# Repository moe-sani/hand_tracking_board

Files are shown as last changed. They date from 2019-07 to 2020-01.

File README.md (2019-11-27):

# hand_tracking_board

    branch name: red_55
    hardware version: RT Exo Data v1.0
    Processor: Arduino M0 Pro (Native USB)

* author: Mohammad Fattahi Sani
* Email: fattahi.m91@gmail.com

----------

 This package contains the following branches: 
 * red_55 : this is the branch for teleoperating the davinci and 3 finger tools. this is for small boards
 * master: this branch was used to collect data in surgical tests using 11 sensors and old board with multiplexr
 * red_80 :  small board configured to work with BNO080 sensors (not finalized yet)
 * DEV_BNO080 :  the vidor4000 board configured to work with BNO080 sensors (not finalized yet)

----------

This version is customized for reading 7 BNO55 sensors. The software only reads I2C zero wich is connected to the connectors on the bottom left of the board ( when holding it with usb on the right side)

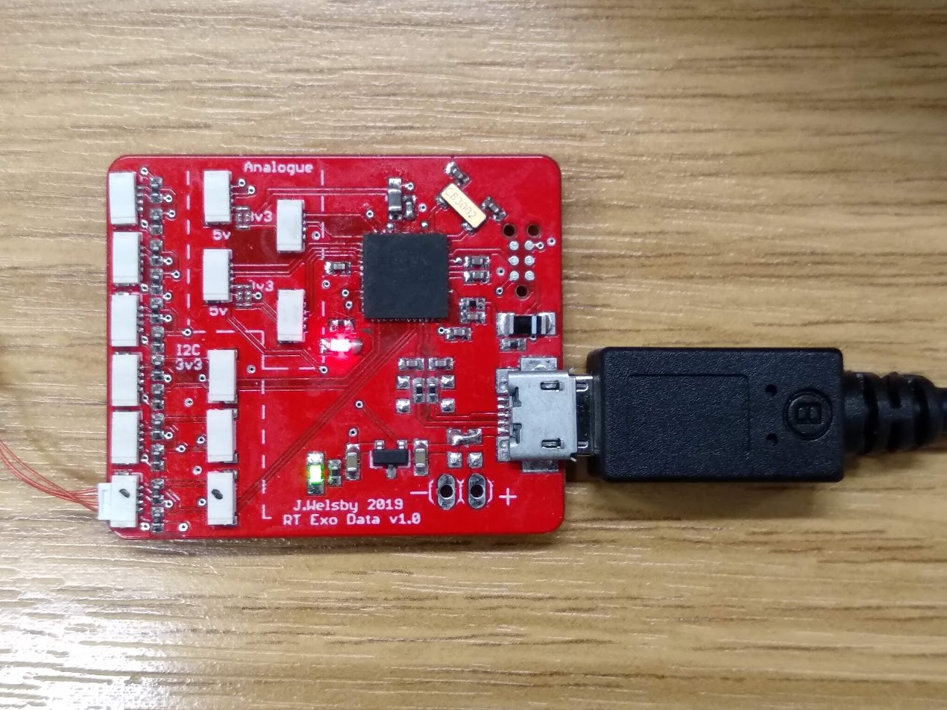
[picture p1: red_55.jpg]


## Sensors:

the sensors must have I2C address translator chip on them. The address on the chip can be selected using the provided resistor values.

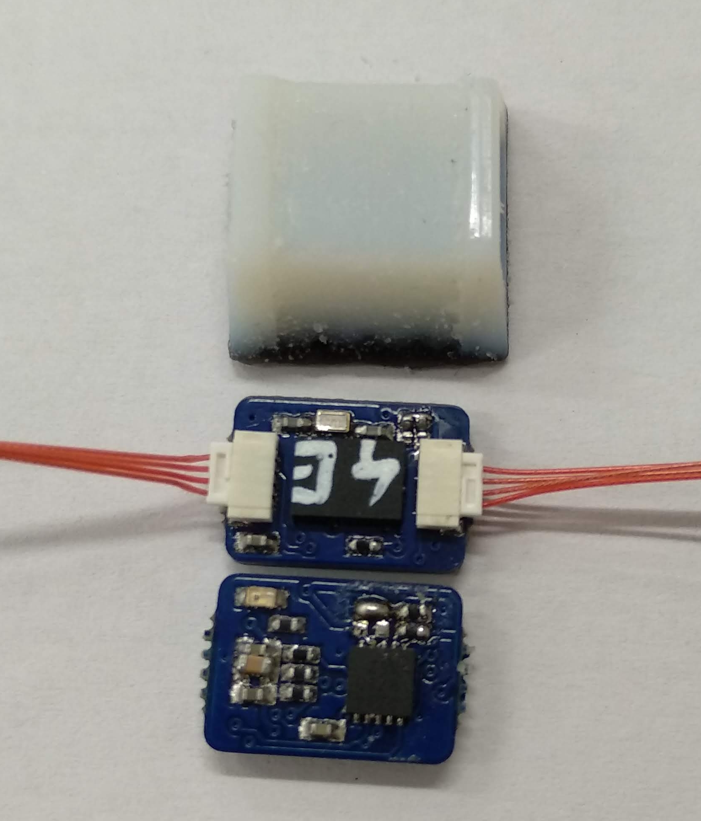
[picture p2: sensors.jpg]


The specific address for each sensor board then should be provided to the software at initializing step of the software. Following is showing how you can set diffrent sensor addresses to the board:

    imu_sensor imu_sensor0=imu_sensor(0,0,0x48);
    imu_sensor imu_sensor1=imu_sensor(1,0,0x28);
    imu_sensor imu_sensor2=imu_sensor(2,0,0x47);
    imu_sensor imu_sensor3=imu_sensor(3,0,0x27);
    imu_sensor imu_sensor4=imu_sensor(4,0,0x2C);
    imu_sensor imu_sensor5=imu_sensor(5,0,0x21);
    imu_sensor imu_sensor6=imu_sensor(6,0,0x68);

This means that for example sensor0 has the address of 0x48. So that specific sensor has be located on the hand on the location defined for sensor0.
## How To Program:

1. you must have arduino program installed on your computer.
2. you must have Arduino M0 Pro (Native USB) driver installed as follows:
    
    navigate to Tools> Boards > Board Manager> install:Arduino SAMD Boards (32-bits ARM Cortex-M0+) by arduino.

3. select the following board: Arduino M0 Pro (Native USB) 

### Required libraries in Arduino:
Please install the following libraries from Arduino Library manager:

    Adafruit BNO055 (version 1.1.8)
    Adafruit Unified Sensor (version 1.0.3)

after you followed the steps, you can simply connect the usb to the board, select the correct usb in the arduino and upload the program.

in the command window, you will first see the initialization steps, for a few seconds, and then the sensor information will be streaming.

here is the sample of data you will see repeatedly:

    > {"S0":[0,0,0,10000], "S1":[3377,-247,-9177,-2073], "S2":[0,0,0,10000], "S3":[0,0,0,10000] }
    > { "C0":[3,3,3,3], "C1":[3,3,3,1], "C2":[3,3,3,3], "C3":[3,3,3,3]} 

the first line is actuall sensory information and the second line is the calibration values (0~3) . 

in this example, it can be noticed that only S1/C1 is connected to the board and the other values are not valid.

    ("S0":[0,0,0,10000]) means that the sensor is not connected).

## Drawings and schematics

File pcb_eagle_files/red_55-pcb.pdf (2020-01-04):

## SAMD21G18A_QFN 100nF ¹⁰⁰nF MH²⁰²⁹⁻³⁰⁰Y

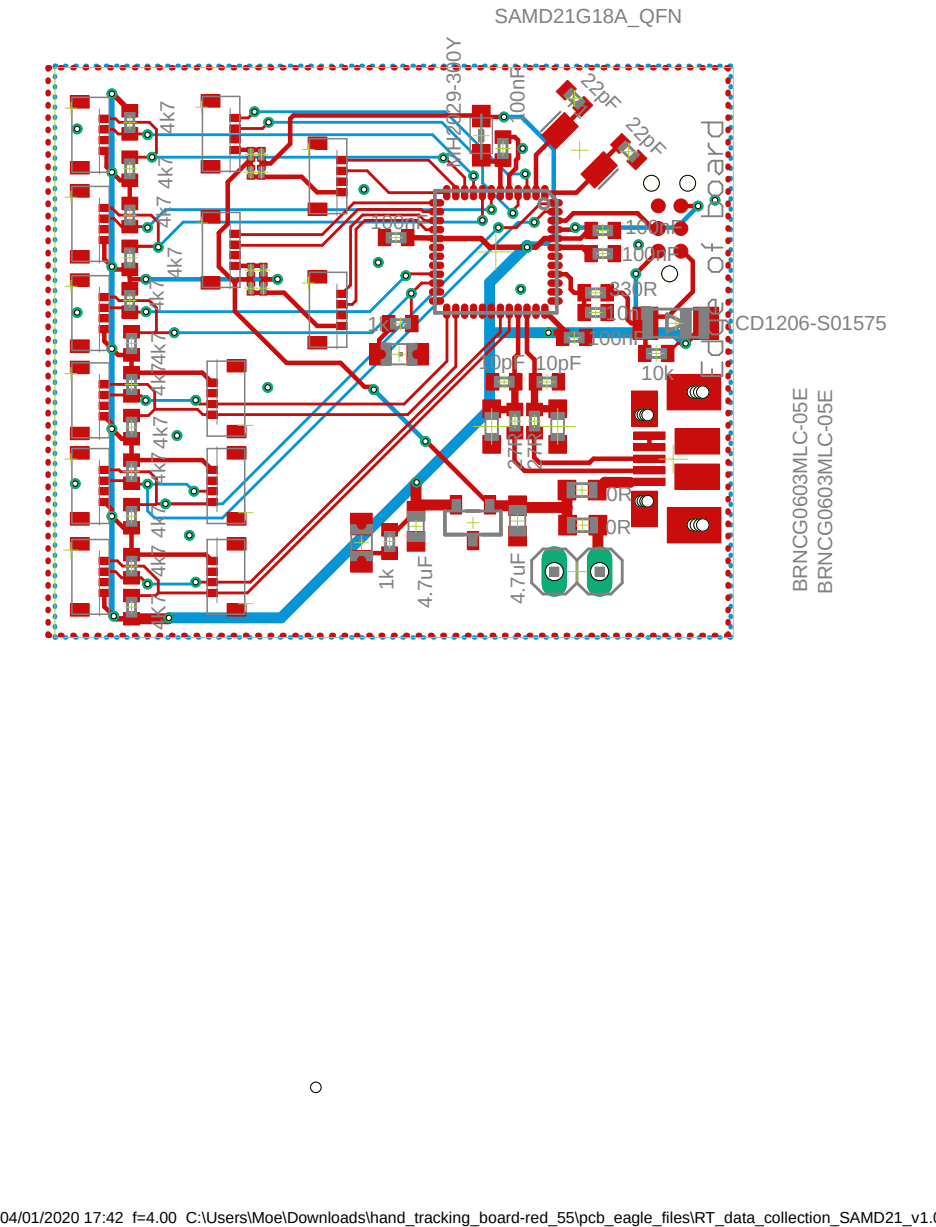
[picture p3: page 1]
BRNCG⁰⁶⁰³MLC⁻⁰⁵E BRNCG⁰⁶⁰³MLC⁻⁰⁵E

04/01/2020 17:42 f=4.00 C:\Users\Moe\Downloads\hand_tracking_board-red_55\pcb_eagle_files\RT_data_collection_SAMD21_v1.0_auto.brd

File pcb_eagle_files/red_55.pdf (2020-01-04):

04/01/2020 17:40 f=0.75 C:\Users\Moe\Downloads\hand_tracking_board-red_55\pcb_eagle_files\RT_data_collection_SAMD21_v1.0_auto.sch (Sheet: 1/3) VDD

# GND +3V³

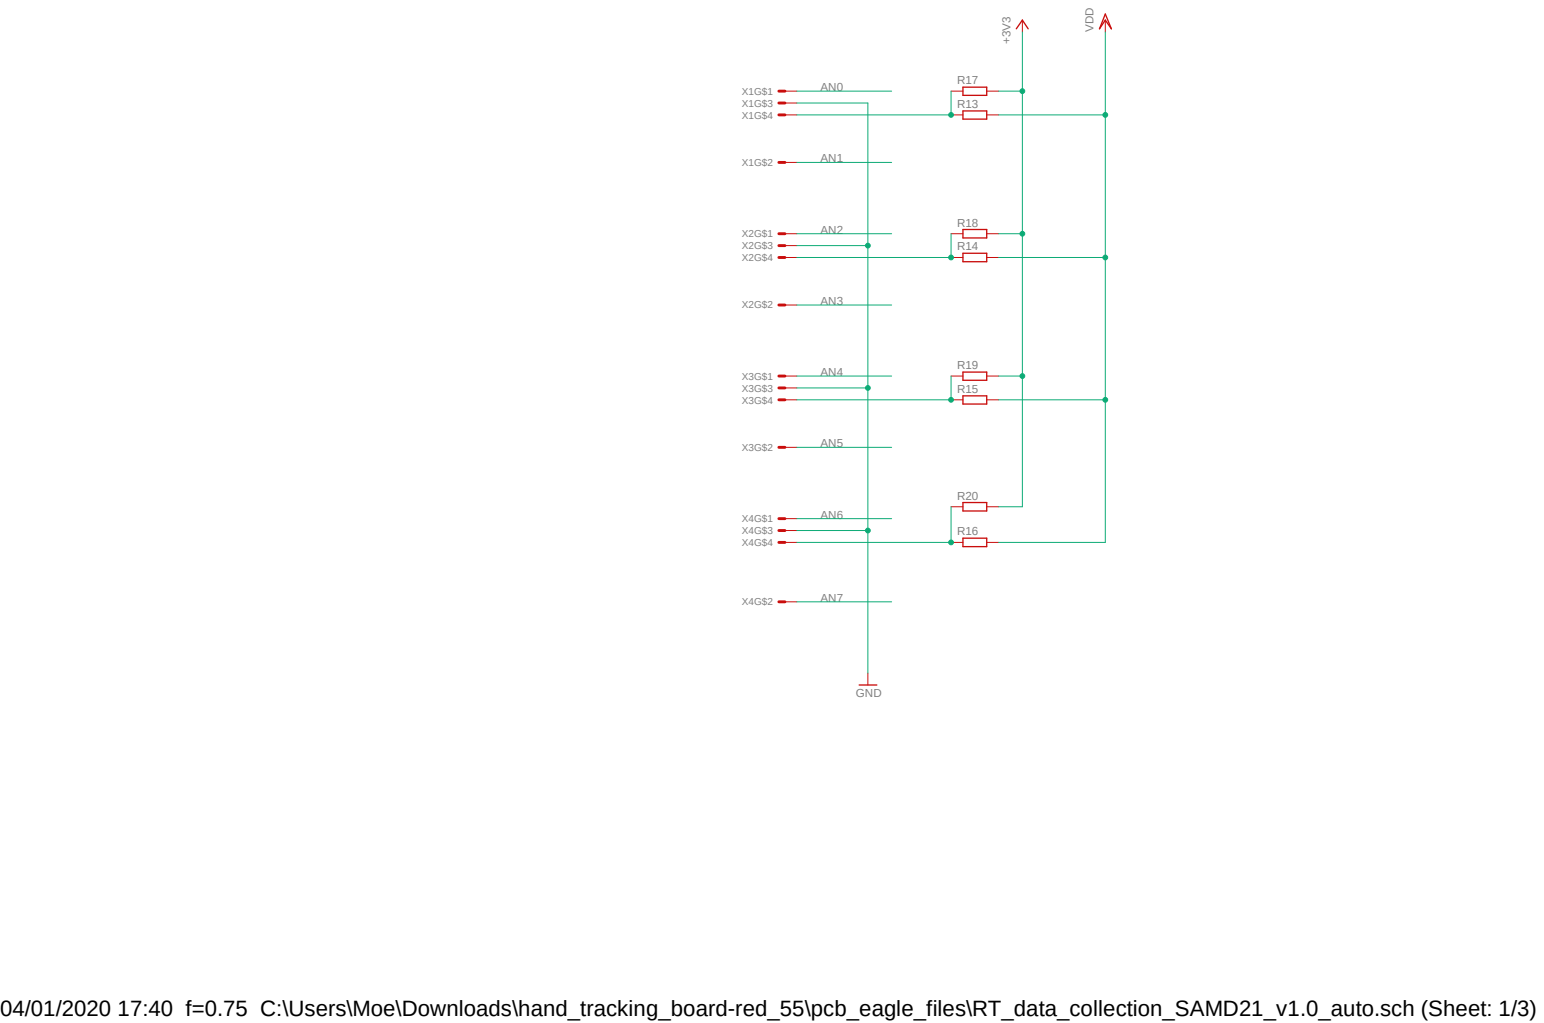
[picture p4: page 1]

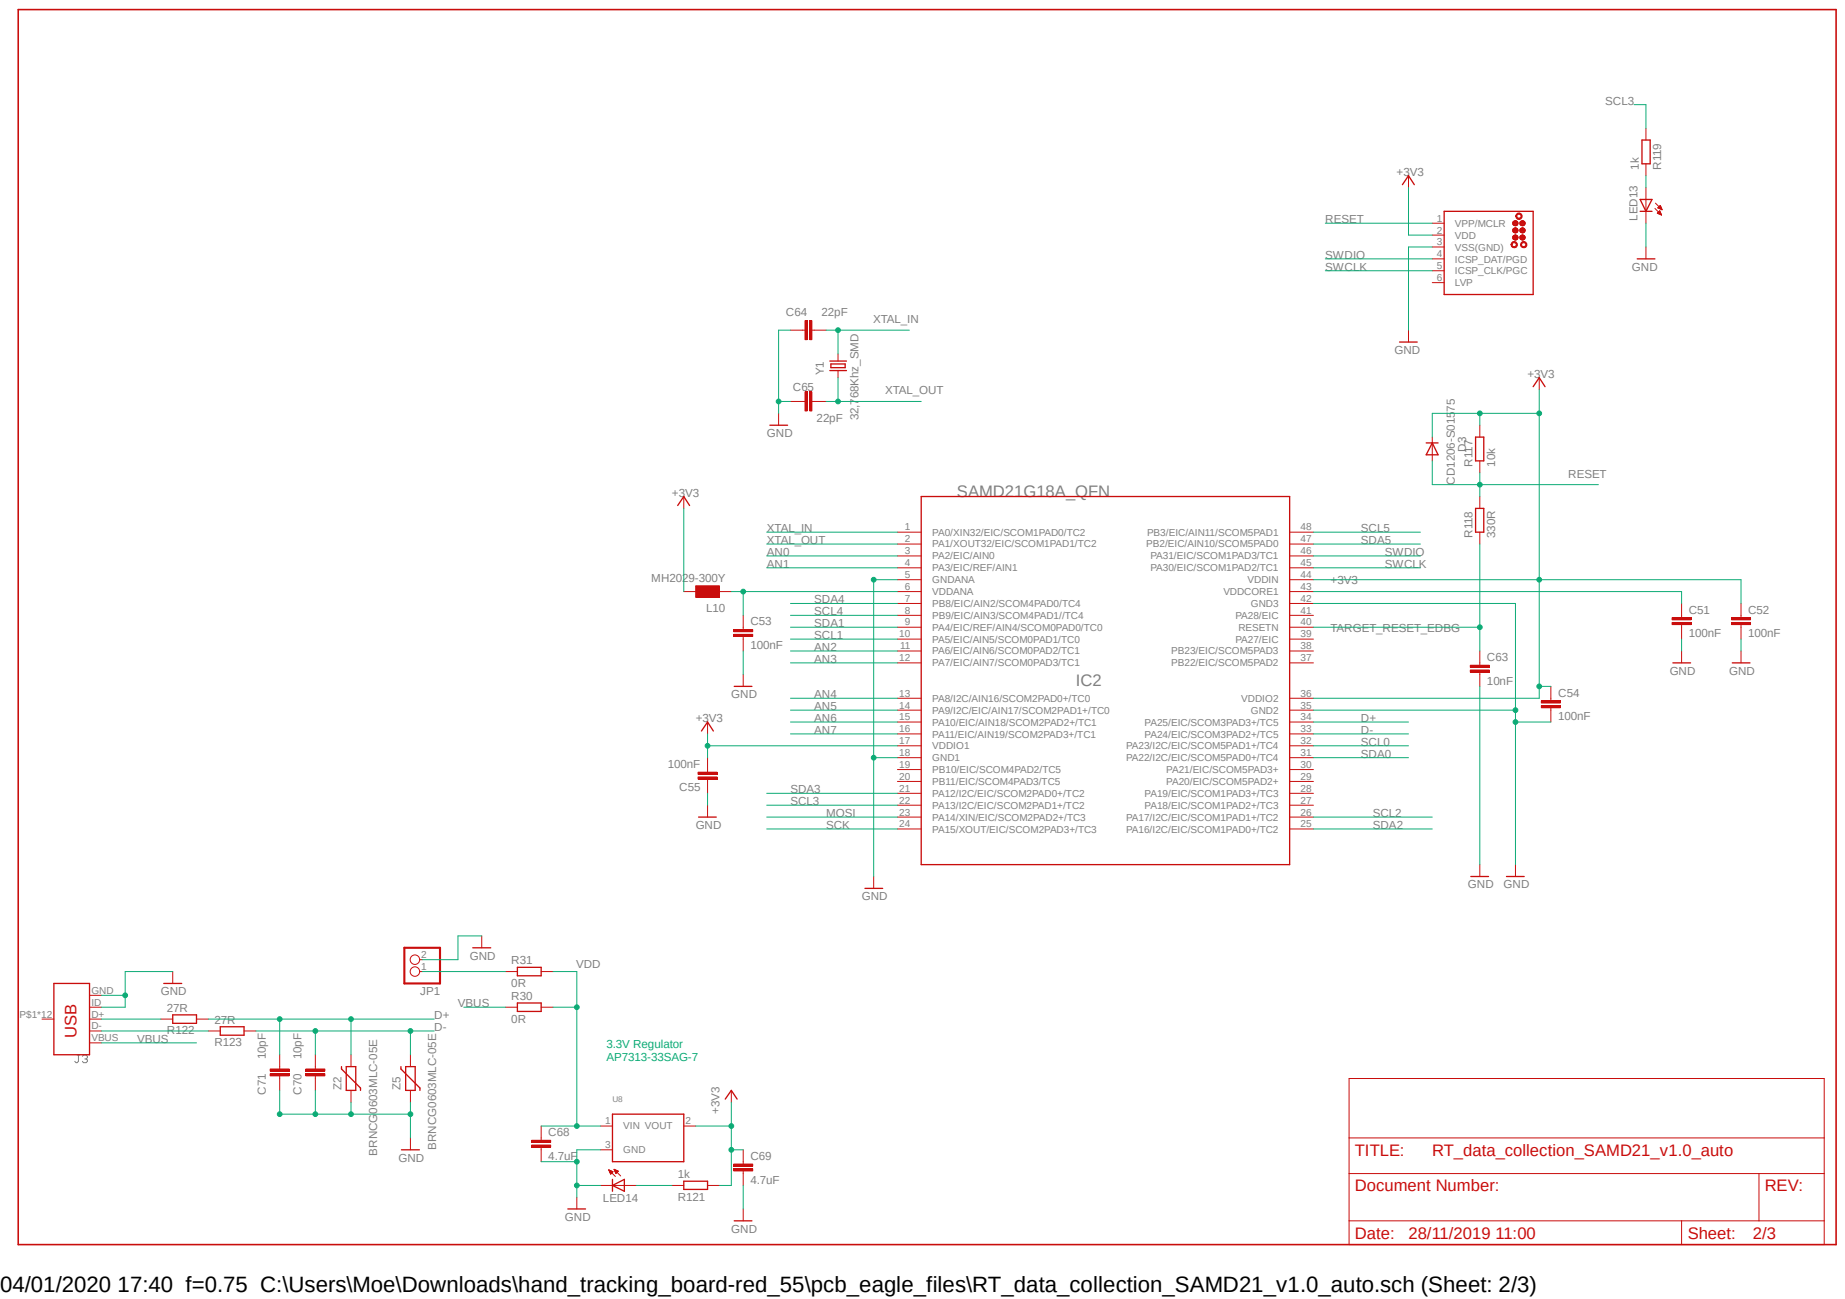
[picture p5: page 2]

GND¹⁰k 330R CD¹²⁰⁶⁻S⁰¹⁵⁷⁵ ³²,768Khz_SMD

C63 R¹¹⁷ R¹¹⁸ D³ Y¹

Document Number: | REV:

Date: 28/11/2019 11:00 | Sheet: 2/3

04/01/2020 17:40 f=0.75 C:\Users\Moe\Downloads\hand_tracking_board-red_55\pcb_eagle_files\RT_data_collection_SAMD21_v1.0_auto.sch (Sheet: 2/3)

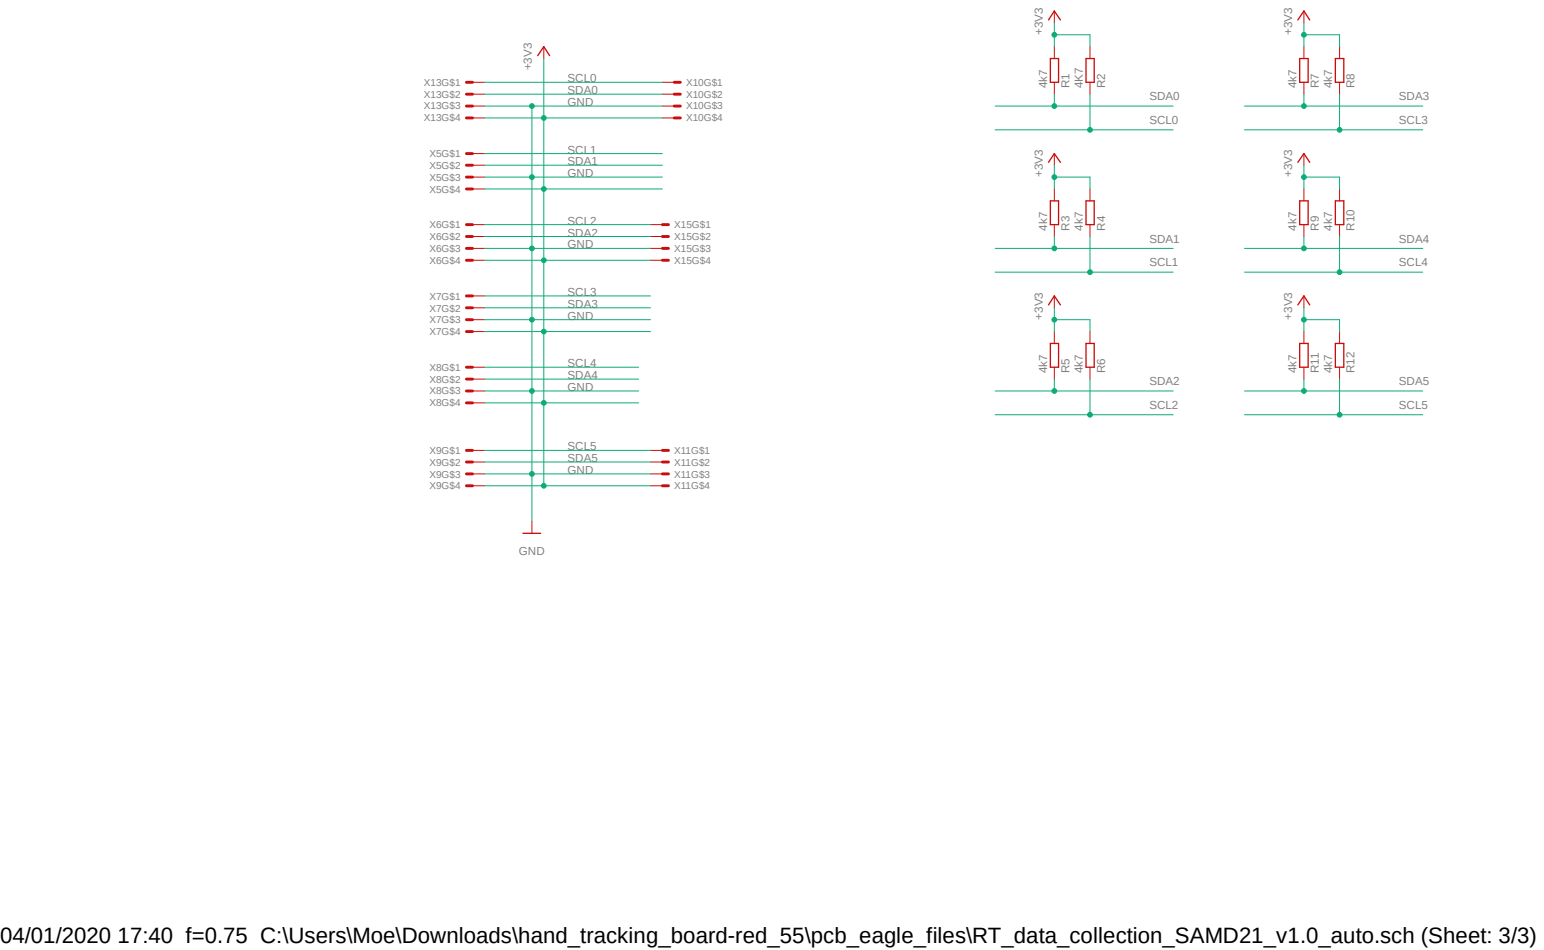
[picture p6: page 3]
GND; R¹⁰ R¹¹; R¹²; SDA0; SCL0; SDA1; SCL1; SDA2; SCL2; SDA4; SCL4; SDA5; SCL5; SDA3; SCL3

04/01/2020 17:40 f=0.75 C:\Users\Moe\Downloads\hand_tracking_board-red_55\pcb_eagle_files\RT_data_collection_SAMD21_v1.0_auto.sch (Sheet: 3/3) ⁺³V³

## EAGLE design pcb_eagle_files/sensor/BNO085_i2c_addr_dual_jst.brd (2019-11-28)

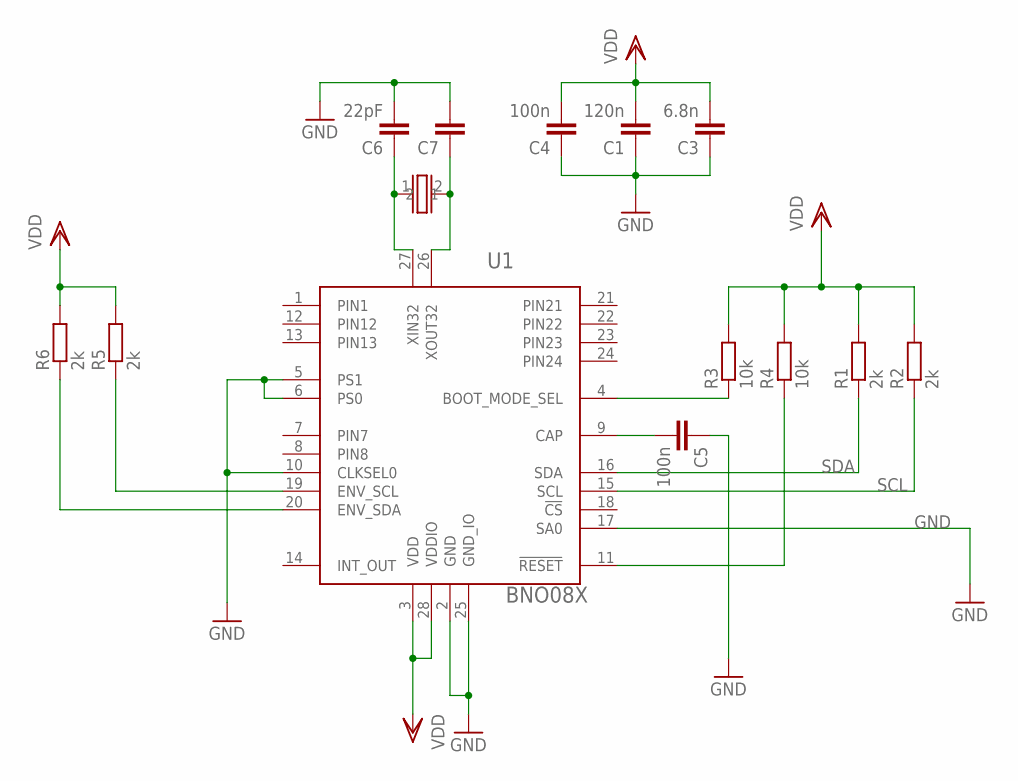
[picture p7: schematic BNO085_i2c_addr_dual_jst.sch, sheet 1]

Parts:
C1: 120n; C0402
C3: 6.8n; C0402
C4, C5: 100n; C0402
C6: 22pF; C0402
C7: C-EUC0402; C0402
R1, R2, R5, R6: 2k; R0402
R3, R4: 10k; R0402
U1: BNO08X; LGA-28_3.80X5.20/0.5
U$1: ABS05

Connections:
GND: C1.1, C3.1, C4.1, C5.1, C6.2, C7.2, U1.2 (GND), U1.5 (PS1), U1.6 (PS0), U1.10 (CLKSEL0), U1.17 (SA0), U1.25 (GND_IO); also elsewhere on the board
unnamed: C6.1, U1.27 (XIN32), U$1.1
unnamed: C7.1, U1.26 (XOUT32), U$1.2
unnamed: C5.2, U1.9 (CAP)
unnamed: R3.1, U1.4 (BOOT_MODE_SEL)
unnamed: R5.1, U1.19 (ENV_SCL)
unnamed: R4.1, U1.11 (!RESET)
unnamed: R6.1, U1.20 (ENV_SDA)
SCL: R2.1, U1.15 (SCL); also elsewhere on the board
SDA: R1.1, U1.16 (SDA); also elsewhere on the board
VDD: C1.2, C3.2, C4.2, R1.2, R2.2, R3.2, R4.2, R5.2, R6.2, U1.3 (VDD), U1.28 (VDDIO); also elsewhere on the board

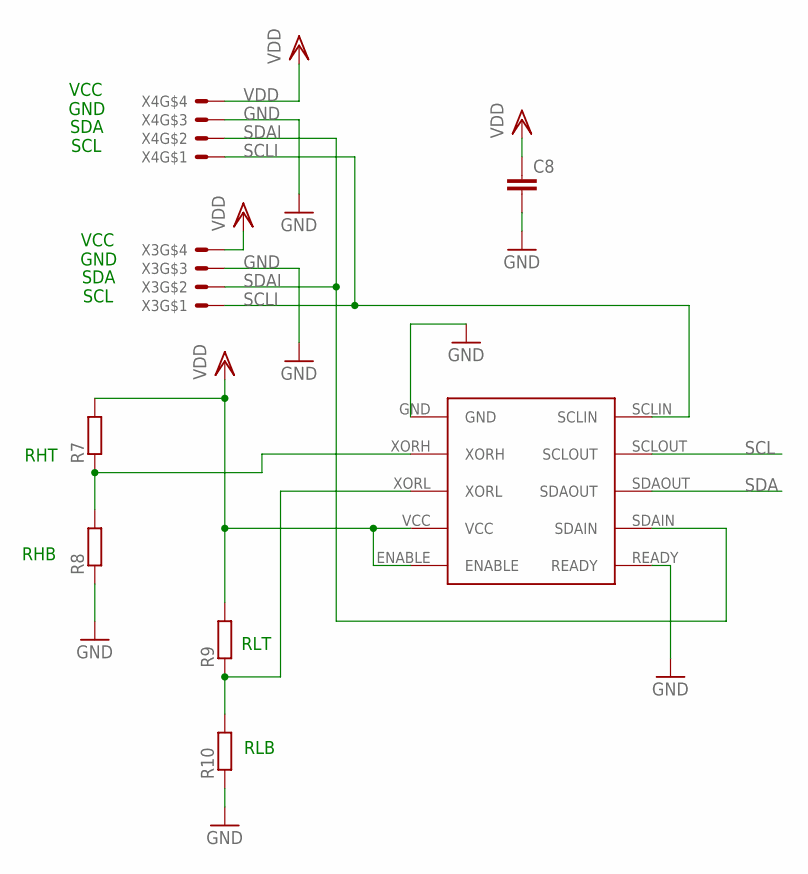
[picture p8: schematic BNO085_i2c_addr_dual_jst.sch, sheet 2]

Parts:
C8: C-EUC0402; C0402
R7, R8, R9, R10: R-EU_R0402; R0402
U$3: LIC4316; DD-DFN-10
X3, X4: SM04B-XSRS; SM04B-XSRS-ETB

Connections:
GND: C8.2, R8.1, R10.1, U$3.GND, U$3.READY, X3.3, X4.3; also elsewhere on the board
unnamed: R7.1, R8.2, U$3.XORH
unnamed: R9.1, R10.2, U$3.XORL
SCL: U$3.SCLOUT; also elsewhere on the board
SCLI: U$3.SCLIN, X3.1, X4.1
SDA: U$3.SDAOUT; also elsewhere on the board
SDAI: U$3.SDAIN, X3.2, X4.2
VDD: C8.1, R7.2, R9.2, U$3.ENABLE, U$3.VCC, X3.4, X4.4; also elsewhere on the board

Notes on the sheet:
SCL
SDA
VCC
GND
RHT
RHB
RLT
RLB

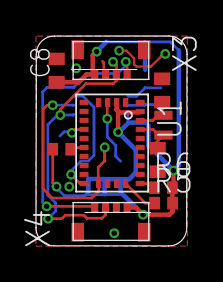
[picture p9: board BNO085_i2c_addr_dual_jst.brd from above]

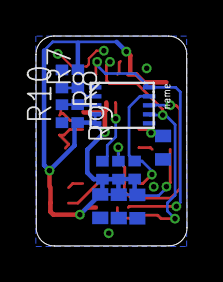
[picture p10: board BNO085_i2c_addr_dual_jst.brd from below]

Board: 2 copper layers, 8.4 x 11.7 mm, 24 parts (12 on the bottom side), 15 nets.

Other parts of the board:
LOGO3: OSHW-LOGOS; OSHW-LOGO-S
U$2: BQ_LOGO_MEDIUM

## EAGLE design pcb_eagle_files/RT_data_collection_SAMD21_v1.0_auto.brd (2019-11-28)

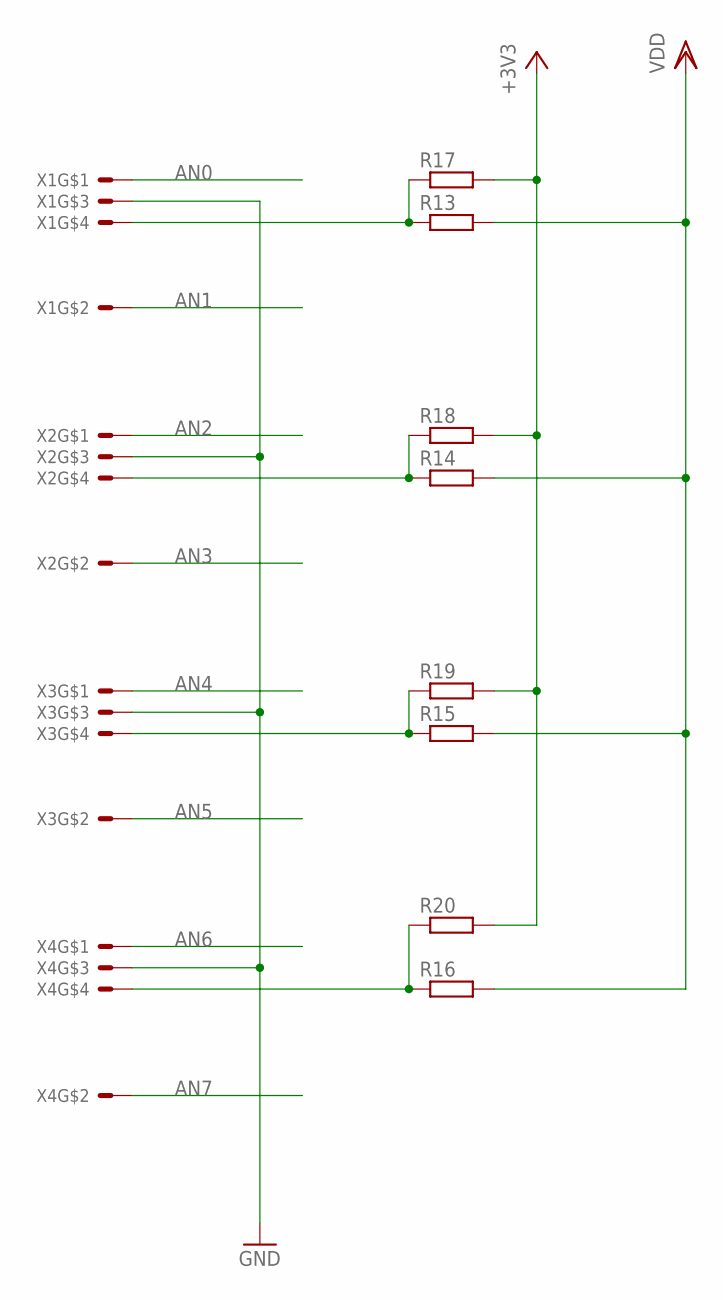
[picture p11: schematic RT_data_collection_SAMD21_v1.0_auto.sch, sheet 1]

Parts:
R13, R14, R15, R16, R17, R18, R19, R20: R-EU_R0201; R0201
X1, X3: CON-JST2_SM04B-XSRS; CON-JST2_SM04B-XSRS-ETB
X2, X4: SM04B-XSRS; SM04B-XSRS-ETB

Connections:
+3V3: R17.2, R18.2, R19.2, R20.2; also elsewhere on the board
AN0: X1.1; also elsewhere on the board
AN1: X1.2; also elsewhere on the board
AN2: X2.1; also elsewhere on the board
AN3: X2.2; also elsewhere on the board
AN4: X3.1; also elsewhere on the board
AN5: X3.2; also elsewhere on the board
AN6: X4.1; also elsewhere on the board
AN7: X4.2; also elsewhere on the board
GND: X1.3, X2.3, X3.3, X4.3; also elsewhere on the board
unnamed: R16.1, R20.1, X4.4
unnamed: R14.1, R18.1, X2.4
unnamed: R15.1, R19.1, X3.4
unnamed: R13.1, R17.1, X1.4
VDD: R13.2, R14.2, R15.2, R16.2; also elsewhere on the board

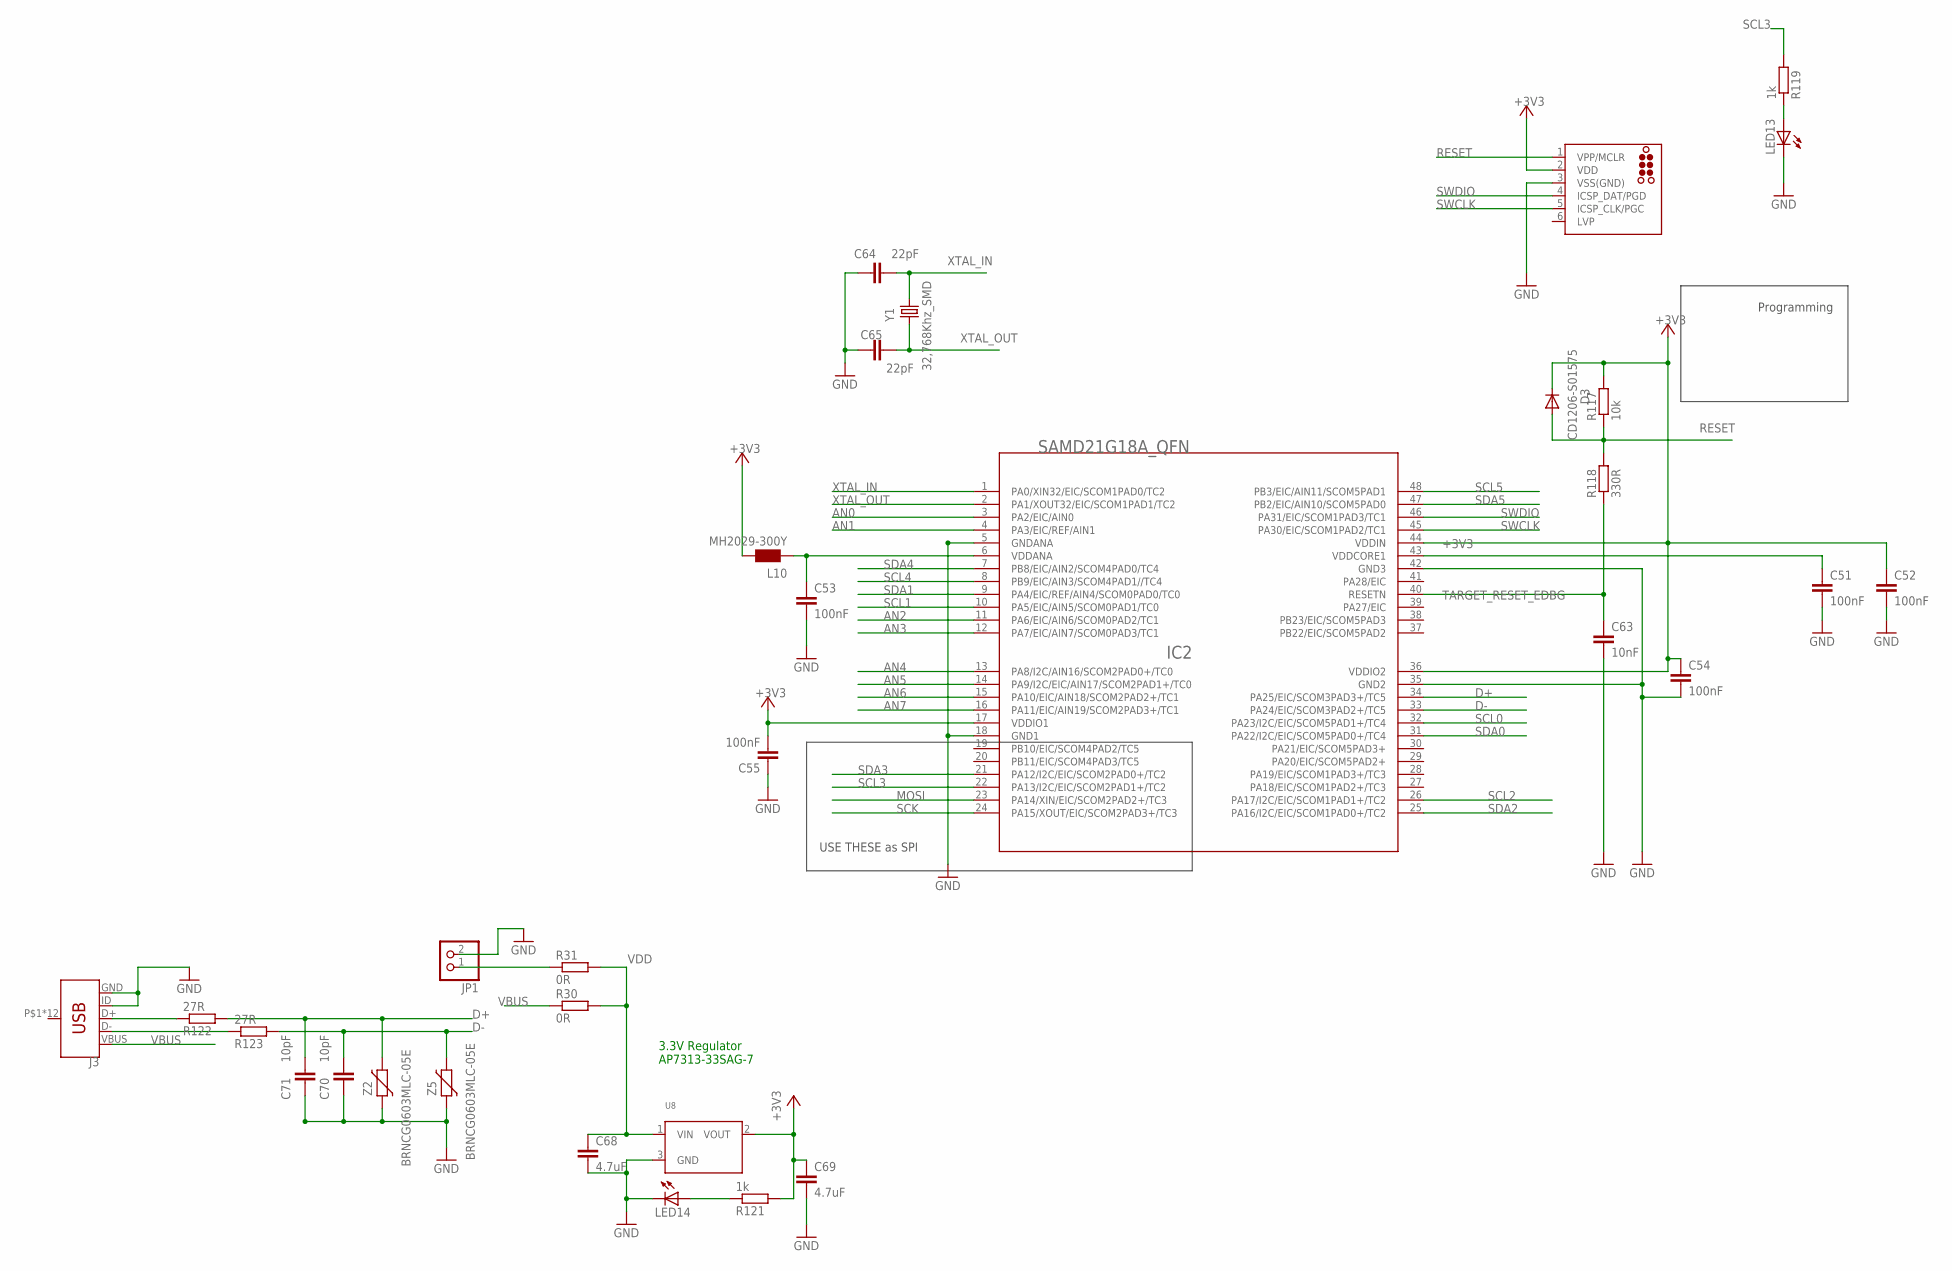
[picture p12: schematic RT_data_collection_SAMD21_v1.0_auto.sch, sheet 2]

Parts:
C51, C52, C53, C54, C55: 100nF; C0402
C63: 10nF; C0402
C64, C65: 22pF; C0402
C68, C69: 4.7uF; C0603
C70, C71: 10pF; C0402
D3: CD1206-S01575; MINIMELF
IC2: SAMD21G18A_QFN
J2: TC2030-MCP-NL
J3: USB_MICRO-B; USB-MICROB-PTH-WIDE
JP1: PINHD-1X2; 1X02
L10: MH2029-300Y; 0805
LED13, LED14: LEDCHIPLED_0805; CHIPLED_0805
R30, R31: 0R; R0603
R117: 10k; R0402
R118: 330R; R0402
R119, R121: 1k; R0402
R122, R123: 27R; R0402
U8: VREG_SOT23; SOT23-R
Y1: 32,768Khz_SMD; CRISTALLI_RESONATOR_EPSON_FC_145
Z2, Z5: BRNCG0603MLC-05E; CT/CN0603

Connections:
+3V3: C52.1, C54.1, C55.2, C69.1, D3.C, IC2.17 (VDDIO1), IC2.36 (VDDIO2), IC2.44 (VDDIN), J2.2 (VDD), L10.2, R117.2, R121.2, U8.2 (VOUT); also elsewhere on the board
AN0: IC2.3 (PA2/EIC/AIN0); also elsewhere on the board
AN1: IC2.4 (PA3/EIC/REF/AIN1); also elsewhere on the board
AN2: IC2.11 (PA6/EIC/AIN6/SCOM0PAD2/TC1); also elsewhere on the board
AN3: IC2.12 (PA7/EIC/AIN7/SCOM0PAD3/TC1); also elsewhere on the board
AN4: IC2.13 (PA8/I2C/AIN16/SCOM2PAD0+/TC0); also elsewhere on the board
AN5: IC2.14 (PA9/I2C/EIC/AIN17/SCOM2PAD1+/TC0); also elsewhere on the board
AN6: IC2.15 (PA10/EIC/AIN18/SCOM2PAD2+/TC1); also elsewhere on the board
AN7: IC2.16 (PA11/EIC/AIN19/SCOM2PAD3+/TC1); also elsewhere on the board
D+: C71.2, IC2.34 (PA25/EIC/SCOM3PAD3+/TC5), R122.2, Z2.2
D-: C70.2, IC2.33 (PA24/EIC/SCOM3PAD2+/TC5), R123.2, Z5.2
GND: C51.2, C52.2, C53.2, C54.2, C55.1, C63.2, C64.1, C65.1, C68.2, C69.2, C70.1, C71.1, IC2.5 (GNDANA), IC2.18 (GND1), IC2.35 (GND2), IC2.42 (GND3), J2.3 (VSS(GND)), J3.GND, J3.ID, JP1.2, LED13.C, LED14.C, U8.3 (GND), Z2.1, Z5.1; also elsewhere on the board
MOSI: IC2.23 (PA14/XIN/EIC/SCOM2PAD2+/TC3)
unnamed: J3.D+, R122.1
unnamed: J3.D-, R123.1
unnamed: C51.1, IC2.43 (VDDCORE1)
unnamed: JP1.1, R31.1
unnamed: C53.1, IC2.6 (VDDANA), L10.1
unnamed: LED13.A, R119.1
unnamed: LED14.A, R121.1
RESET: D3.A, J2.1 (VPP/MCLR), R117.1, R118.2
SCK: IC2.24 (PA15/XOUT/EIC/SCOM2PAD3+/TC3)
SCL0: IC2.32 (PA23/I2C/EIC/SCOM5PAD1+/TC4); also elsewhere on the board
SCL1: IC2.10 (PA5/EIC/AIN5/SCOM0PAD1/TC0); also elsewhere on the board
SCL2: IC2.26 (PA17/I2C/EIC/SCOM1PAD1+/TC2); also elsewhere on the board
SCL3: IC2.22 (PA13/I2C/EIC/SCOM2PAD1+/TC2), R119.2; also elsewhere on the board
SCL4: IC2.8 (PB9/EIC/AIN3/SCOM4PAD1//TC4); also elsewhere on the board
SCL5: IC2.48 (PB3/EIC/AIN11/SCOM5PAD1); also elsewhere on the board
SDA0: IC2.31 (PA22/I2C/EIC/SCOM5PAD0+/TC4); also elsewhere on the board
SDA1: IC2.9 (PA4/EIC/REF/AIN4/SCOM0PAD0/TC0); also elsewhere on the board
SDA2: IC2.25 (PA16/I2C/EIC/SCOM1PAD0+/TC2); also elsewhere on the board
SDA3: IC2.21 (PA12/I2C/EIC/SCOM2PAD0+/TC2); also elsewhere on the board
SDA4: IC2.7 (PB8/EIC/AIN2/SCOM4PAD0/TC4); also elsewhere on the board
SDA5: IC2.47 (PB2/EIC/AIN10/SCOM5PAD0); also elsewhere on the board
SWCLK: IC2.45 (PA30/EIC/SCOM1PAD2/TC1), J2.5 (ICSP_CLK/PGC)
SWDIO: IC2.46 (PA31/EIC/SCOM1PAD3/TC1), J2.4 (ICSP_DAT/PGD)
TARGET_RESET_EDBG: C63.1, IC2.40 (RESETN), R118.1
VBUS: J3.VBUS, R30.1
VDD: C68.1, R30.2, R31.2, U8.1 (VIN); also elsewhere on the board
XTAL_IN: C64.2, IC2.1 (PA0/XIN32/EIC/SCOM1PAD0/TC2), Y1.P$2 (2)
XTAL_OUT: C65.2, IC2.2 (PA1/XOUT32/EIC/SCOM1PAD1/TC2), Y1.P$1 (1)

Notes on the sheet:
3.3V Regulator AP7313-33SAG-7
USE THESE as SPI
Programming

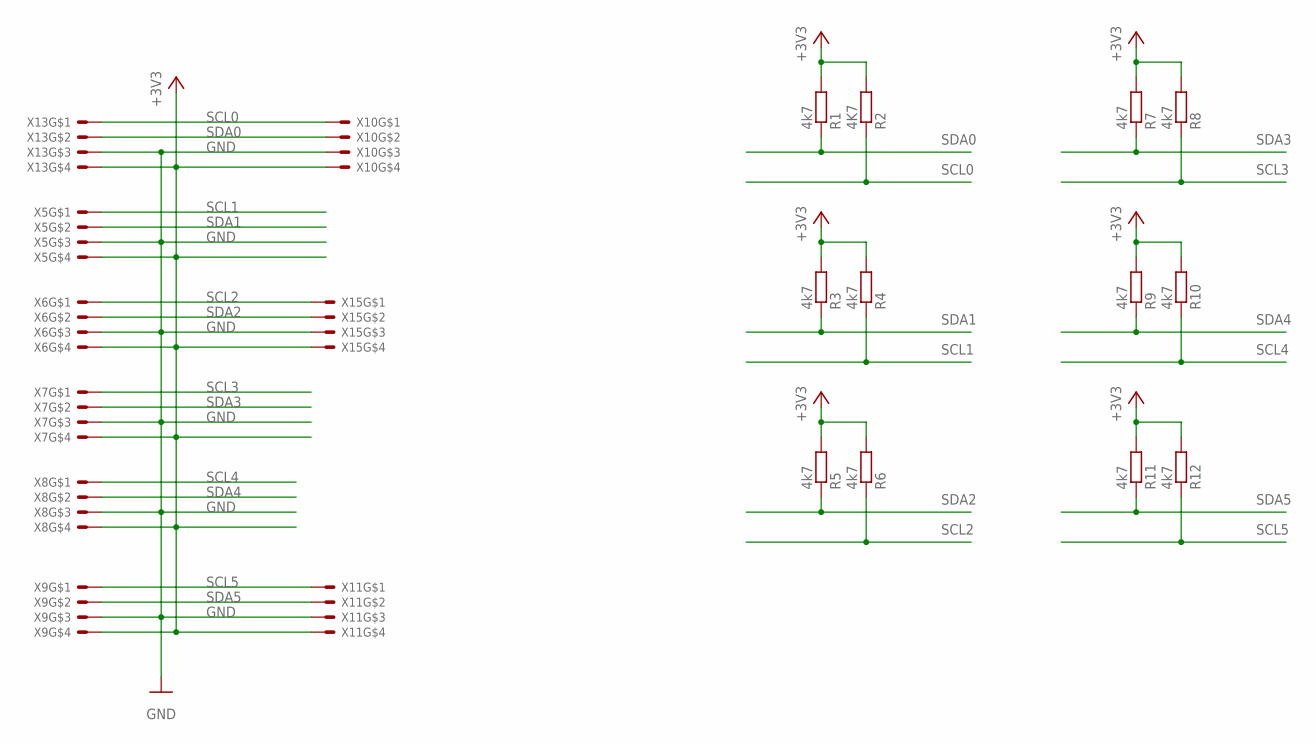
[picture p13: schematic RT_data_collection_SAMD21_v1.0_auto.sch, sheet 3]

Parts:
R1, R3, R4, R5, R6, R7, R8, R9, R10, R11, R12: 4k7; R0402
R2: 4K7; R0402
X5, X6, X7, X8, X9, X10, X11, X13, X15: SM04B-XSRS; SM04B-XSRS-ETB

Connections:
+3V3: R1.2, R2.2, R3.2, R4.2, R5.2, R6.2, R7.2, R8.2, R9.2, R10.2, R11.2, R12.2, X5.4, X6.4, X7.4, X8.4, X9.4, X10.4, X11.4, X13.4, X15.4; also elsewhere on the board
GND: X5.3, X6.3, X7.3, X8.3, X9.3, X10.3, X11.3, X13.3, X15.3; also elsewhere on the board
SCL0: R2.1, X10.1, X13.1; also elsewhere on the board
SCL1: R4.1, X5.1; also elsewhere on the board
SCL2: R6.1, X6.1, X15.1; also elsewhere on the board
SCL3: R8.1, X7.1; also elsewhere on the board
SCL4: R10.1, X8.1; also elsewhere on the board
SCL5: R12.1, X9.1, X11.1; also elsewhere on the board
SDA0: R1.1, X10.2, X13.2; also elsewhere on the board
SDA1: R3.1, X5.2; also elsewhere on the board
SDA2: R5.1, X6.2, X15.2; also elsewhere on the board
SDA3: R7.1, X7.2; also elsewhere on the board
SDA4: R9.1, X8.2; also elsewhere on the board
SDA5: R11.1, X9.2, X11.2; also elsewhere on the board

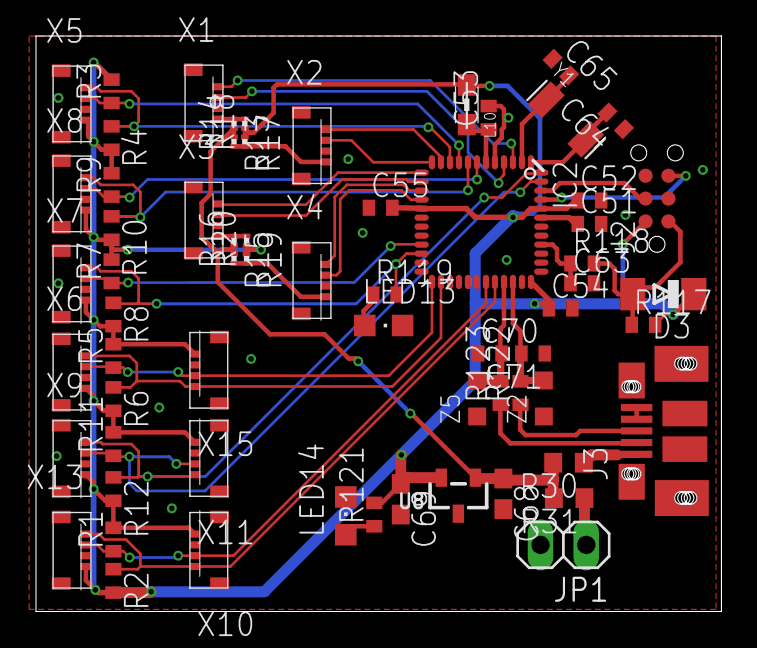
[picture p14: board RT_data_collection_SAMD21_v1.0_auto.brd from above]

Board: 2 copper layers, 38.1 x 32.0 mm, 65 parts (0 on the bottom side), 43 nets.

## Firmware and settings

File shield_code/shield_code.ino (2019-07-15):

/**************************************************************************/
/*
    IMU SERIAL CODE

    History:

    Ver 01: just sends sensor A and B in a bit mode
    Ver_02: send a jason code and read it on computer: works for one sensor, speed:20hz
    Ver_03: wow, this appearantly works on 100 hertz!
    Ver_04: adding more i2c sensors....... this works with 50Hz appearantly!
    Ver_05: adding EEPROM >> storage function works well
    Ver_07: adding strain gauge:works well
    Ver_08: reading 4 set of sensors...
    Ver_09: this version can read up to 4 channels
    Ver_10: trying to have memory part inside the class:tested with Person
    Ver_13 : until now, one sensor calibration store and send works fine. now I gonna try all sensors... there is a problem, after all of the calibrtions, program stops!
    ver_14: restore calibration from predefined data:done, send all sensors with something like 33Hz
    Ver_16: so far so good
    
*/
/**************************************************************************/




#include <Wire.h>
#include <Adafruit_Sensor.h>
#include <Adafruit_BNO055.h>
#include <utility/imumaths.h>
#include "HX711.h"



//#include<EEPROM.h>

typedef struct {
  boolean valid;
  char name[100];
  char surname[100];
} Person;

struct sensorOutputs {
    int ox;
    int oy;
    int oz;
};




// The two BNO055 modules, bnoB has the ADR pin wired to 3.3v to change its i2c address
// Both are wired: SCL to analog 5, SDA to analog 4, VIN to 5v, GRN to ground

/* This code uses I2C Protocol  */

/**************************************************************************/
/*
    GLOBAL VARIABLES
*/
/**************************************************************************/

#define BNO055_SAMPLERATE_DELAY_MS (1)
// Include EEPROM-like API for FlashStorage
//#include <FlashAsEEPROM.h>
#include <FlashStorage.h>
//FlashStorage(my_flash_store, adafruit_bno055_offsets_t);
//FlashStorage(my_flash_store0, Person);
FlashStorage(my_flash_store0, adafruit_bno055_offsets_t);
FlashStorage(my_flash_store1, adafruit_bno055_offsets_t);
FlashStorage(my_flash_store2, adafruit_bno055_offsets_t);
FlashStorage(my_flash_store3, adafruit_bno055_offsets_t);
FlashStorage(my_flash_store4, adafruit_bno055_offsets_t);
FlashStorage(my_flash_store5, adafruit_bno055_offsets_t);
FlashStorage(my_flash_store6, adafruit_bno055_offsets_t);
FlashStorage(my_flash_store7, adafruit_bno055_offsets_t);
FlashStorage(my_flash_store8, adafruit_bno055_offsets_t);
FlashStorage(my_flash_store9, adafruit_bno055_offsets_t);
FlashStorage(my_flash_store10, adafruit_bno055_offsets_t);
FlashStorage(my_flash_store11, adafruit_bno055_offsets_t);

//__attribute__((__aligned__(256))) \
//static const uint8_t PPCAT(_data,my_flash_store2)[(sizeof(Person)+255)/256*256] = { }; \
//FlashStorageClass<Person> my_flash_store2(PPCAT(_data,my_flash_store2));
// pattern is : accel , mag, gyro, accel radious, mag radious
static const adafruit_bno055_offsets_t Predefined_Calibration[]= {{21975, 0, 3928, 8192, 3, 0 ,  127, 0, 21517, 0,2 },  //0
                                                                    {21975, 0, 3928, 8192, 3, 0 ,  127, 0, 21517, 0,2 },//1
                                                                    {18, -18, 12, -150, -307, -470 , -1, 0, -1 , 1000, 742},//2
                                                                    { 24, 39, 10 , -761, -438, 305 , 2, 1, 3 , 1000, 947},//3
                                                                    { 5, 35, 10 , -387, -216, -525 , -2, -2, 1 , 1000, 573},//4
                                                                    {-7, 24, 10 , 813, 403, -29 , -2, -1, -1 , 1000, 570},//5
                                                                    {16, 26, 15 , -52, -77, -578 , 0, 0, 0 , 1000, 556},//6
                                                                    {-7, 56, 1 , 263, 150, -383 , -3, -4, 0 , 1000, 541},//7
                                                                    {14, -6, 17 , -1055, 257, 742 , -1, -1, -1 , 1000, 576},//8
                                                                    {14, -6, 17 , -1051, 263, 740, -1, -1, -1 , 1000, 596},//9
                                                                    {11, 21, 35 , -86, 122, -872 , -2, -2, 0 , 1000, 646},//10
                                                                    {11, 21, 35 , -79, 114, -865 , -2, -2, 0 , 1000, 704}};//11

//Adafruit_BNO055 bno0A = Adafruit_BNO055(55, 0x28); /* A Sensor Address */
//Adafruit_BNO055 bno0B = Adafruit_BNO055(56, 0x29); /* B Sensor Address */



int val=0;

float sensorA_OX;
float sensorA_OY;
float sensorA_OZ;
float sensorB_OX;
float sensorB_OY;
float sensorB_OZ;

// HX711 circuit wiring
const int LOADCELL_DOUT_PIN = 4;
const int LOADCELL_SCK_PIN = 5;
HX711 scale;
long scale_data;
unsigned int i=0;
#define TCA9548A_I2C_ADDRESS  0x70
#define PIN_S0 0
#define PIN_S1 1
#define PIN_S2 2
#define LED_SHIELD_1 7
#define LED_SHIELD_2 6
#define LED_SHIELD_3 A6


/**************************************************************************/
/*
    FUNCTION LIST
*/
/**************************************************************************/
void serial_send(float data);
void Init_bno();
void displaySensorDetails(void);
void displayCalStatusA(void);
void displayCalStatusB(void);
void displaySensorOffsetsA(const adafruit_bno055_offsets_t &calibDataA);
void displaySensorOffsetsB(const adafruit_bno055_offsets_t &calibDataB);

boolean enableMuxPort(byte portNumber);
boolean disableMuxPort(byte portNumber);


/**************************************************************************/
/*
    class for sensors
*/
/**************************************************************************/
class imu_sensor {
    private:
        byte pinLED;
        uint8_t address;
        uint8_t channel;
        uint8_t sensor_id;
        Adafruit_BNO055 bno;

    public:
        imu_sensor(uint8_t sensor_id,uint8_t channel, uint8_t address)
        {
            this->channel=channel;
            this->address=address;
            this-> sensor_id=sensor_id;
            bno = Adafruit_BNO055(sensor_id, address); /* A Sensor Address */
        }

        void init()
        {
            byte value = 0;
            Serial.print("Initalizing sensor ");
            Serial.print(this-> sensor_id);
            Serial.print("on port:");
            Serial.print(this->channel);
            Serial.print("on address:");
            Serial.print(this->address);
            Serial.println(" ");

            enableMuxPort(this->channel);
            Serial.println("test:============");
            Wire.beginTransmission(this->address);
            Wire.write((uint8_t)0x00);
            Wire.endTransmission();
            Wire.requestFrom(this->address, (byte)1);
            value = Wire.read();
            Serial.println(value);         // print the character
            delay(500);
            if(!bno.begin())
              {
                Serial.print("Ooops, no BNO055 detected ... Check your wiring or I2C ADDR!");
                Serial.println(" ");
              }
            disableMuxPort(this->channel);
        }

        void calibrate (FlashStorageClass<adafruit_bno055_offsets_t> my_flash_store)
        {
            Serial.print("Calibration for sensor ");
            Serial.print(this-> sensor_id);
            Serial.print("on port:");
            Serial.print(this->channel);
            Serial.print("on address:");
            Serial.print(this->address);
            Serial.println(" ");
            enableMuxPort(this->channel);

            adafruit_bno055_offsets_t calibrationDataA;
            // Read the content of "my_flash_store" into the "owner" variable
            calibrationDataA = my_flash_store.read();
            this->displaySensorOffsets(calibrationDataA);

           delay(500);
            sensor_t sensorA;

            //bno.getSensor(&sensorA);

            /* Display some basic information on this sensor A and B*/
            this->displaySensorDetails();

            /* Optional: Display current status A and B*/
            //this->displaySensorStatus();

            bno.setExtCrystalUse(true);

            sensors_event_t eventA;

            if(calibrationDataA.accel_offset_x==0)
            {
                Serial.println("Please Calibrate Sensor: ");
                while(!bno.isFullyCalibrated()){
                  bno.getEvent(&eventA);
                  Serial.print("X'A': ");
                  Serial.print(eventA.orientation.x, 4);
                  Serial.print("\tY'A': ");
                  Serial.print(eventA.orientation.y, 4);
                  Serial.print("\tZ'A':  ");
                  Serial.print(eventA.orientation.z, 4);

                  this->displayCalStatus();
                  Serial.println("");
                  delay(BNO055_SAMPLERATE_DELAY_MS);
                }
                Serial.println("\n\nCalibration Is Done!");
                adafruit_bno055_offsets_t newCaliA;
                bno.getSensorOffsets(newCaliA);
                this->displaySensorOffsets(newCaliA);
                // Save new calibration to arduino memory
                Serial.println("\n\nStoring calibration data to EEPROM...");

                my_flash_store.write(newCaliA);
            }
            else
            {
                bno.setSensorOffsets(calibrationDataA);
                Serial.println("Calibration data restored!");
            }
            disableMuxPort(this->channel);
            delay(1000);

        }

        ///**************************************************************************/
        /*
            Displays some basic information on this sensor from the unified
            sensor API sensor_t type (see Adafruit_Sensor for more information)
        */
        /**************************************************************************/


        void displaySensorDetails(void)
        {
          //enableMuxPort(this->channel);
          sensor_t sensorA;

          bno.getSensor(&sensorA);

          Serial.println("------------------------------------");
          Serial.print  ("Sensor:       "); Serial.println(sensorA.name);
          Serial.print  ("Driver Ver:   "); Serial.println(sensorA.version);
          Serial.print  ("Unique ID:    "); Serial.println(sensorA.sensor_id);
          Serial.print  ("Max Value:    "); Serial.print(sensorA.max_value); Serial.println(" xxx");
          Serial.print  ("Min Value:    "); Serial.print(sensorA.min_value); Serial.println(" xxx");
          Serial.print  ("Resolution:   "); Serial.print(sensorA.resolution); Serial.println(" xxx");
          Serial.println("------------------------------------");
          Serial.println("");
          delay(500);
          //disableMuxPort(this->channel);
        }

        /**************************************************************************/
        /*
            Display sensor calibration status
        */
        /**************************************************************************/
        void displayCalStatus(void)
        {
          //enableMuxPort(this->channel);
          /* Get the four calibration values (0..3) */
          /* Any sensor data reporting 0 should be ignored, */
          /* 3 means 'fully calibrated" */

          uint8_t systemA, gyroA, accelA, magA;
          systemA = gyroA = accelA = magA = 0;
          bno.getCalibration(&systemA, &gyroA, &accelA, &magA);

          /* The data should be ignored until the system calibration is > 0 */
          Serial.print("\t");
          if (!systemA)
          {
            Serial.print("! ");
          }

          /* Display the individual values */
          Serial.print("Sys'A':");
          Serial.print(systemA, DEC);
          Serial.print(" G'A':");
          Serial.print(gyroA, DEC);
          Serial.print(" A'A':");
          Serial.print(accelA, DEC);
          Serial.print(" M'A':");
          Serial.print(magA, DEC);
          //disableMuxPort(this->channel);
        }

         void displaySensorOffsets(const adafruit_bno055_offsets_t &calibDataA)
        {
            //enableMuxPort(this->channel);
            Serial.print("Accelerometer: ");
            Serial.print(calibDataA.accel_offset_x); Serial.print(" ");
            Serial.print(calibDataA.accel_offset_y); Serial.print(" ");
            Serial.print(calibDataA.accel_offset_z); Serial.print(" ");

            Serial.print("\nGyro: ");
            Serial.print(calibDataA.gyro_offset_x); Serial.print(" ");
            Serial.print(calibDataA.gyro_offset_y); Serial.print(" ");
            Serial.print(calibDataA.gyro_offset_z); Serial.print(" ");

            Serial.print("\nMag: ");
            Serial.print(calibDataA.mag_offset_x); Serial.print(" ");
            Serial.print(calibDataA.mag_offset_y); Serial.print(" ");
            Serial.print(calibDataA.mag_offset_z); Serial.print(" ");

            Serial.print("\nAccel Radius: ");
            Serial.print(calibDataA.accel_radius);

            Serial.print("\nMag Radius: ");
            Serial.print(calibDataA.mag_radius);
            //disableMuxPort(this->channel);
        }

        sensorOutputs read()
        {
            enableMuxPort(this->channel);
            sensors_event_t eventA;
            bno.getEvent(&eventA);
            sensorOutputs newOutputs;

            newOutputs.oz=(int)(eventA.orientation.x*10);//Note that I changed this to make it consistent with datasheet cordinate system
            newOutputs.oy=(int)(eventA.orientation.y*10);
            newOutputs.ox=(int)(eventA.orientation.z*10);
            disableMuxPort(this->channel);
            return newOutputs;
        }

        void restorePredefinedCalibration()
        {
            Serial.println("Restoring Predefined Calibration for sensor: ");
            Serial.print(this-> sensor_id);
            Serial.print("on port:");
            Serial.print(this->channel);
            Serial.print("on address:");
            Serial.print(this->address);
            Serial.println(" ");
            enableMuxPort(this->channel);
            enableMuxPort(this->channel);
            adafruit_bno055_offsets_t calibrationDataA = Predefined_Calibration[this->sensor_id];
            bno.setSensorOffsets(calibrationDataA);
            this->displaySensorOffsets(calibrationDataA);
            Serial.println("Predefined Calibration data restored!");
            disableMuxPort(this->channel);

        }


        //void store(Person owner,FlashStorageClass<adafruit_bno055_offsets_t> my_flash_store)
        //{

          //my_flash_store.write(owner);
          //delay(5000);



        //}
        //void restore(FlashStorageClass<Person> my_flash_store)
        //{
          //Serial.println("restoring values for sensor:");
          //Serial.print(this-> sensor_id);
          //Serial.println(" ");
          //Person owner;
          //owner = my_flash_store.read();
          //Serial.print("name: ");
//          Serial.print(owner.name);
//          Serial.print("surname:");
//          Serial.print(owner.surname);

        //}

};


imu_sensor imu_sensor0=imu_sensor(0,0,0x28);
imu_sensor imu_sensor1=imu_sensor(1,0,0x29);
imu_sensor imu_sensor2=imu_sensor(2,1,0x28);
imu_sensor imu_sensor3=imu_sensor(3,1,0x29);
imu_sensor imu_sensor4=imu_sensor(4,2,0x28);
imu_sensor imu_sensor5=imu_sensor(5,2,0x29);
imu_sensor imu_sensor6=imu_sensor(6,3,0x28);
imu_sensor imu_sensor7=imu_sensor(7,3,0x29);
imu_sensor imu_sensor8=imu_sensor(8,4,0x28);
imu_sensor imu_sensor9=imu_sensor(9,4,0x29);
imu_sensor imu_sensor10=imu_sensor(10,5,0x28);
imu_sensor imu_sensor11=imu_sensor(11,5,0x29);

/**************************************************************************/
/*
    Arduino setup function (automatically called at startup)
*/
/**************************************************************************/
void setup(void)
{
  pinMode(LED_BUILTIN, OUTPUT);
  //pinMode(interruptPin, INPUT_PULLUP);
  pinMode(13, INPUT_PULLUP);
  pinMode(14, INPUT_PULLUP);
  digitalWrite(LED_BUILTIN,0);
    pinMode(PIN_S0, OUTPUT);
    pinMode(PIN_S1, OUTPUT);
    pinMode(PIN_S2, OUTPUT);
    pinMode(LED_SHIELD_1, OUTPUT);
    pinMode(LED_SHIELD_2, OUTPUT);
    pinMode(LED_SHIELD_3, OUTPUT);
    digitalWrite(PIN_S0, LOW);
    digitalWrite(PIN_S1, LOW);
    digitalWrite(PIN_S2, LOW);

  Wire.begin();
  Serial.begin(230400);
  Serial.println("Dual BNO055 Test");  Serial.println("");
  Serial.println("hellowwwwwwwwwwwwwwwwwwwwwwwwwww");
  //test serial port
  delay(1000);
  Serial.println("5");
    delay(1000);
  Serial.println("4");
    delay(1000);
  Serial.println("3");
    delay(1000);
  Serial.println("2");
    delay(1000);
  Serial.println("1");
  
//  enableMuxPort(0);
//
//  delay(500);
//  byte value = 0;
//  //Serial.println("loop:");
//  Serial.println("Wire0x28 port0:============");
//  Wire.beginTransmission(0x28);
//  Wire.write((uint8_t)0x00);
//  Wire.endTransmission();
//  Wire.requestFrom(0x28, (byte)1);
//  value = Wire.read();
//  Serial.println(value);         // print the character
//  delay(1000);
//  Serial.println("Wire0x29 port0:============");
//  Wire.beginTransmission(0x29);
//  Wire.write((uint8_t)0x00);
//  Wire.endTransmission();
//  Wire.requestFrom(0x29, (byte)1);
//  value = Wire.read();
//  Serial.println(value);         // print the character
//
//  disableMuxPort(0);
  delay(1000);
  
  //Init_bno();
  //attachInterrupt(digitalPinToInterrupt(interruptPin), send_data_ISR, RISING );
  imu_sensor0.init();
  imu_sensor1.init();
  imu_sensor2.init();
  imu_sensor3.init();
  imu_sensor4.init();
  imu_sensor5.init();
  imu_sensor6.init();
  imu_sensor7.init();
  imu_sensor8.init();
  imu_sensor9.init();
  imu_sensor10.init();
  imu_sensor11.init();
  delay(1000);

  imu_sensor0.restorePredefinedCalibration();
  imu_sensor1.restorePredefinedCalibration();
  imu_sensor2.restorePredefinedCalibration();
  imu_sensor3.restorePredefinedCalibration();
  imu_sensor4.restorePredefinedCalibration();
  imu_sensor5.restorePredefinedCalibration();
  imu_sensor6.restorePredefinedCalibration();
  imu_sensor7.restorePredefinedCalibration();
  imu_sensor8.restorePredefinedCalibration();
  imu_sensor9.restorePredefinedCalibration();
  imu_sensor10.restorePredefinedCalibration();
  imu_sensor11.restorePredefinedCalibration();
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
 void loop(void)
{
  
  digitalWrite(LED_BUILTIN,!digitalRead(LED_BUILTIN));
  digitalWrite(LED_SHIELD_1,!digitalRead(LED_SHIELD_1));
  digitalWrite(LED_SHIELD_2,!digitalRead(LED_SHIELD_2));
  digitalWrite(LED_SHIELD_3,!digitalRead(LED_SHIELD_3));
  //Serial.println("main loop");
  sensorOutputs sensor0;
  sensorOutputs sensor1;
  sensorOutputs sensor2;
  sensorOutputs sensor3;
  sensorOutputs sensor4;
  sensorOutputs sensor5;
  sensorOutputs sensor6;
  sensorOutputs sensor7;
  sensorOutputs sensor8;
  sensorOutputs sensor9;
  sensorOutputs sensor10;
  sensorOutputs sensor11;
  sensor0=imu_sensor0.read();
  sensor1=imu_sensor1.read();
  sensor2=imu_sensor2.read();
  sensor3=imu_sensor3.read();
  sensor4=imu_sensor4.read();
  sensor5=imu_sensor5.read();
  sensor6=imu_sensor6.read();
  sensor7=imu_sensor7.read();
  sensor8=imu_sensor8.read();
  sensor9=imu_sensor9.read();
  sensor10=imu_sensor10.read();
  sensor11=imu_sensor11.read();

  if (scale.is_ready()) {
  scale_data = scale.read();
  //Serial.print("HX711 reading: ");
  //Serial.println(reading);
  } else {
    //Serial.println("HX711 not found.");
  }

  char buffer[300];
  sprintf(buffer, "{\"SC\":[%d], \"S0\":[%d,%d,%d], \"S1\":[%d,%d,%d], \"S2\":[%d,%d,%d], \"S3\":[%d,%d,%d], \"S4\":[%d,%d,%d], \"S5\":[%d,%d,%d], \"S6\":[%d,%d,%d], \"S7\":[%d,%d,%d], \"S8\":[%d,%d,%d], \"S9\":[%d,%d,%d], \"S10\":[%d,%d,%d], \"S11\":[%d,%d,%d]} ",scale_data,sensor0.ox,sensor0.oy,sensor0.oz,sensor1.ox,sensor1.oy,sensor1.oz,sensor2.ox,sensor2.oy,sensor2.oz,sensor3.ox,sensor3.oy,sensor3.oz,sensor4.ox,sensor4.oy,sensor4.oz,sensor5.ox,sensor5.oy,sensor5.oz,sensor6.ox,sensor6.oy,sensor6.oz,sensor7.ox,sensor7.oy,sensor7.oz,sensor8.ox,sensor8.oy,sensor8.oz,sensor9.ox,sensor9.oy,sensor9.oz,sensor10.ox,sensor10.oy,sensor10.oz,sensor11.ox,sensor11.oy,sensor11.oz);
  //sprintf(buffer, "{\"SC\":[%d], \"S0\":[%d,%d,%d], \"S1\":[%d,%d,%d], \"S2\":[%d,%d,%d], \"S3\":[%d,%d,%d], \"S4\":[%d,%d,%d], \"S5\":[%d,%d,%d], \"S6\":[%d,%d,%d], \"S7\":[%d,%d,%d], \"S8\":[%d,%d,%d], \"S9\":[%d,%d,%d], \"S10\":[%d,%d,%d], \"S11\":[%d,%d,%d], \"ST\":[%d,%d,%d]} ",
  //                  scale_data, i++,101,102,sensor0.ox,sensor0.oy,sensor0.oz,120,121,122,130,131,132,140,141,142,150,151,152,160,161,162,170,171,172,180,181,182,190,191,192,200,201,202,210,211,212,220,221,222);

  Serial.println(buffer);
  //Serial.write(0x0D);
  //Serial.write(0x0A);

delay(BNO055_SAMPLERATE_DELAY_MS);
    
}

/**************************************************************************/
/*
    init the sensors
*/
/**************************************************************************/

//Enables a specific port number
boolean enableMuxPort(byte portNumber)
{
  if(portNumber > 7) portNumber = 7;

  //Read the current mux settings
  Wire.requestFrom(TCA9548A_I2C_ADDRESS, 1);
  if(!Wire.available()) return(false); //Error
  byte settings = Wire.read();

  //Set the wanted bit to enable the port
  settings |= (1 << portNumber);

  Wire.beginTransmission(TCA9548A_I2C_ADDRESS);
  Wire.write(settings);
  Wire.endTransmission();

  return(true);
}

//Disables a specific port number
boolean disableMuxPort(byte portNumber)
{
  if(portNumber > 7) portNumber = 7;

  //Read the current mux settings
  Wire.requestFrom(TCA9548A_I2C_ADDRESS, 1);
  if(!Wire.available()) return(false); //Error
  byte settings = Wire.read();

  //Clear the wanted bit to disable the port
  settings &= ~(1 << portNumber);

  Wire.beginTransmission(TCA9548A_I2C_ADDRESS);
  Wire.write(settings);
  Wire.endTransmission();

  return(true);
}

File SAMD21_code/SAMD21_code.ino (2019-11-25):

/**************************************************************************/
/*
# license removed for brevity
'''
author: Mohammad Fattahi Sani
email: fattahi.m91@gmail.com
this code is provided only for SMARTsurg's Internal refrence.
author's permission is required for any kind of partial or whole usage or distribution.
'''


    IMU SerialUSB CODE

*/
/**************************************************************************/




#include <Wire.h>
#include <Adafruit_Sensor.h>
#include <Adafruit_BNO055.h>
#include "wiring_private.h"

///#include <Adafruit_Sensor.h>
//#in/clude <utility/imumaths.h>
//#include "SparkFun_BNO080_Arduino_Library.h"



struct sensorOutputs {
//    int ox;
//    int oy;
//    int oz;
    int x;
    int y;
    int z;
    int w;
};



#define SAMPLERATE_DELAY_MS (1)

static const adafruit_bno055_offsets_t Predefined_Calibration[]= {{21975, 0, 3928, 8192, 3, 0 ,  127, 0, 21517, 0,2 },  //0
                                                                    {21975, 0, 3928, 8192, 3, 0 ,  127, 0, 21517, 0,2 },//1
                                                                    {18, -18, 12, -150, -307, -470 , -1, 0, -1 , 1000, 742},//2
                                                                    { 24, 39, 10 , -761, -438, 305 , 2, 1, 3 , 1000, 947},//3
                                                                    { 5, 35, 10 , -387, -216, -525 , -2, -2, 1 , 1000, 573},//4
                                                                    { 5, 35, 10 , -387, -216, -525 , -2, -2, 1 , 1000, 573},//5
                                                                    {-7, 24, 10 , 813, 403, -29 , -2, -1, -1 , 1000, 570}};//6

float sensorA_OX;
float sensorA_OY;
float sensorA_OZ;
float sensorB_OX;
float sensorB_OY;
float sensorB_OZ;

#define PIN_LED 43
#define PIN_SDA2 11
#define PIN_SCL2 13

TwoWire Wire2(&sercom1, PIN_SDA2, PIN_SCL2);   //(&PERIPH_WIRE, PIN_WIRE_SDA, PIN_WIRE_SCL);


/**************************************************************************/
/*
    FUNCTION LIST
*/
/**************************************************************************/

/**************************************************************************/
/*
    class for sensors
*/
/**************************************************************************/
class imu_sensor {
    private:
        uint8_t address;
        uint8_t channel;
        uint8_t sensor_id;
        //TwoWire myWire;
        TwoWire *myWire;
//        BNO080 myIMU;
        bool isConnected;
        Adafruit_BNO055 bno;

    public:
        //constructor
//        imu_sensor(uint8_t sensor_id, TwoWire *theWire, uint8_t address )
        imu_sensor(uint8_t sensor_id, uint8_t channel, uint8_t address )
        {
            this->channel=channel;
            this->address=address;
            //this->myWire=Wire;
            this-> sensor_id=sensor_id;
            if (channel==2)
            {
                this->bno = Adafruit_BNO055(sensor_id, address, &Wire2); /* A Sensor Address */
                this->myWire = &Wire2;
            }
            else
            {
                this->bno = Adafruit_BNO055(sensor_id, address, &Wire); /* A Sensor Address */
                this->myWire = &Wire;
            }

        }

        void init()
        {
            byte value = 0;
            SerialUSB.println("==========================");
            SerialUSB.print("Initalizing sensor ");
            SerialUSB.print(this-> sensor_id);
            SerialUSB.print("on address:");
            SerialUSB.print(this->address);
            SerialUSB.println(" ");
            SerialUSB.println("WHOAMI register reply:");
            this->myWire->beginTransmission(this->address);
            this->myWire->write((uint8_t)0x00);
            this->myWire->endTransmission();
            this->myWire->requestFrom(this->address, (byte)1);
            value = this->myWire->read();
            SerialUSB.println(value);         // print the character
            delay(500);
            if(!this->bno.begin())
              {
                SerialUSB.print("Ooops, no BNO055 detected ... Check your wiring or I2C ADDR!");
                SerialUSB.println(" ");
                this->isConnected= false;
              }
              else
              {
                this->isConnected= true;
                SerialUSB.println("This sensor is alive!");
              }
        }

        void calibrate ()
        {
            if( this->isConnected)
            {

            SerialUSB.println("Restoring Predefined Calibration for sensor: ");
            SerialUSB.print(this-> sensor_id);
            SerialUSB.print("on address:");
            SerialUSB.print(this->address);
            SerialUSB.println(" ");
            adafruit_bno055_offsets_t calibrationDataA = Predefined_Calibration[this->sensor_id];
            bno.setSensorOffsets(calibrationDataA);
            this->displaySensorOffsets(calibrationDataA);
            SerialUSB.println("Predefined Calibration data restored!");
            SerialUSB.println("\n\nCalibration Is Done!");
            delay(500);
            }
        }
        /**************************************************************************/
        /*
            Display sensor calibration status
        */
        /**************************************************************************/

        void displaySensorDetails(void)
        {
          //enableMuxPort(this->channel);
          sensor_t sensorA;

          bno.getSensor(&sensorA);

          SerialUSB.println("------------------------------------");
          SerialUSB.print  ("Sensor:       "); SerialUSB.println(sensorA.name);
          SerialUSB.print  ("Driver Ver:   "); SerialUSB.println(sensorA.version);
          SerialUSB.print  ("Unique ID:    "); SerialUSB.println(sensorA.sensor_id);
          SerialUSB.print  ("Max Value:    "); SerialUSB.print(sensorA.max_value); SerialUSB.println(" xxx");
          SerialUSB.print  ("Min Value:    "); SerialUSB.print(sensorA.min_value); SerialUSB.println(" xxx");
          SerialUSB.print  ("Resolution:   "); SerialUSB.print(sensorA.resolution); SerialUSB.println(" xxx");
          SerialUSB.println("------------------------------------");
          SerialUSB.println("");
          delay(500);
          //disableMuxPort(this->channel);
        }

        /**************************************************************************/
        /*
            Display sensor calibration status
        */
        /**************************************************************************/
        void displayCalStatus(void)
        {
          //enableMuxPort(this->channel);
          /* Get the four calibration values (0..3) */
          /* Any sensor data reporting 0 should be ignored, */
          /* 3 means 'fully calibrated" */
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

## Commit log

2019-07-29 fixed isconnected+ send calibration values through the serial
    [SAMD21_code.ino]
2019-10-05 first proper version for the red board with BNO080
2019-10-07 still only works for first i2c
2019-10-08 trying to find problem why wire2 doesnt work!
    [SAMD21_code.ino]
2019-10-28 add readme + calibration values
2019-11-25 added 3 more sensors
2019-11-28 added pcb files (not the final versions)
    [BNO085_i2c_addr_dual_jst.brd, BNO085_i2c_addr_dual_jst.sch, RT_data_collection_SAMD21_v1.0_auto.brd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]

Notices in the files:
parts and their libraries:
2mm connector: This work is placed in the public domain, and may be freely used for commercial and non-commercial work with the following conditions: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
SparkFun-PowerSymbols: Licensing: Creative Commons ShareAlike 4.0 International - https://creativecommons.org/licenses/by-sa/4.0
